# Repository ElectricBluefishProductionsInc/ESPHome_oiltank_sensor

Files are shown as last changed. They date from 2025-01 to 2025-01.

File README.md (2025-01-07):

# ESPHome Oil Tank Level Monitor

This project uses ESPHome to configure an ESP32 device for monitoring the oil level in a tank. The device utilizes a VL53L0X distance sensor to measure the distance to the oil surface and calculates the remaining oil volume, daily consumption, and estimated time to depletion. Integration with Home Assistant provides real-time data visualization and tracking.
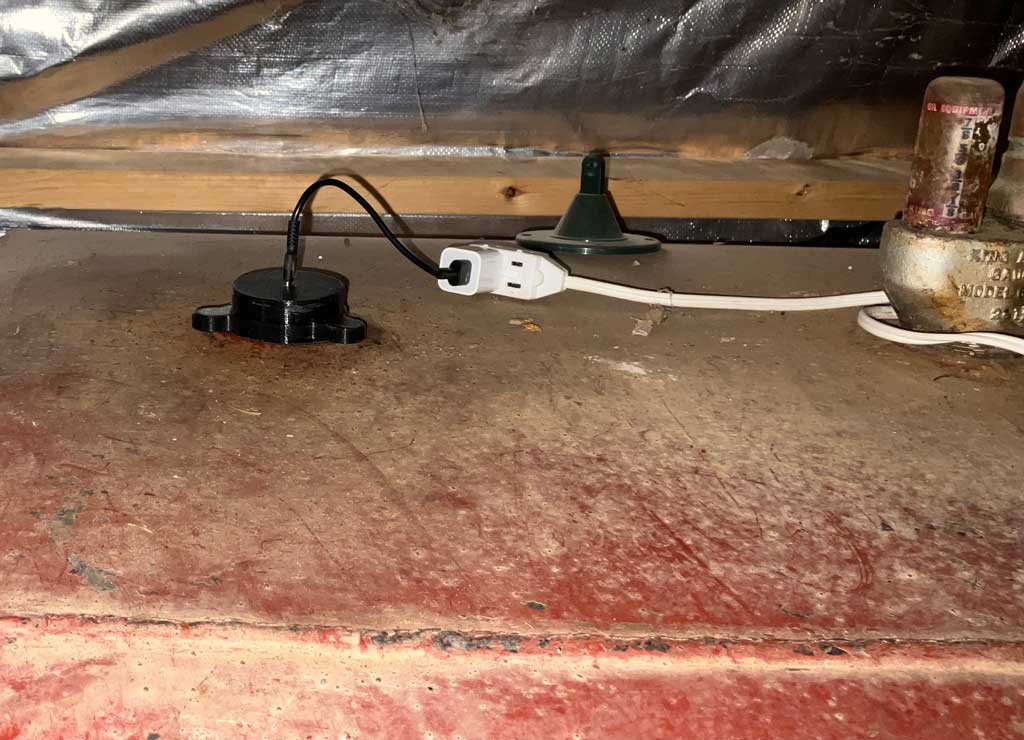
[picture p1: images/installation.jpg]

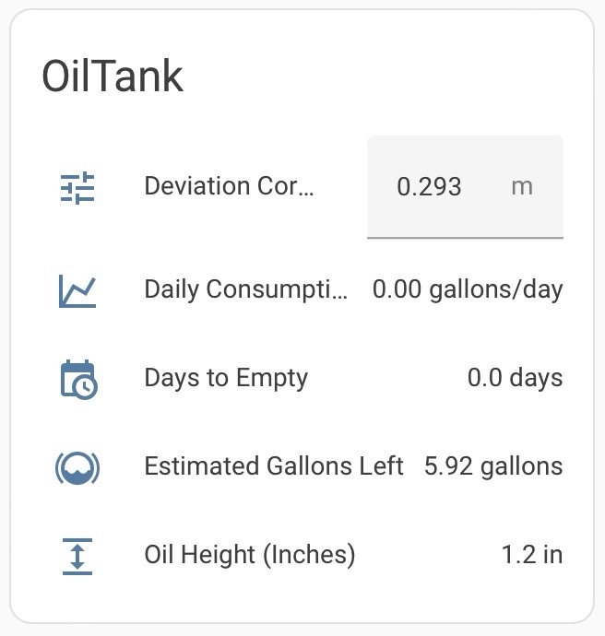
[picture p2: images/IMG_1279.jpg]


## Features

- **Real-Time Monitoring**: Tracks oil height, volume, daily consumption, and estimated days until empty.
- **VL53L0X Sensor Integration**: Measures distance to the oil surface using I2C.
- **Customizable Deviation Correction**: Adjusts measurements for environmental or sensor-specific deviations.
- **Daily Consumption Tracking**: Logs hourly changes to calculate daily oil usage.
- **WiFi Connectivity**: Includes fallback access point (AP) mode for easy troubleshooting.
- **Home Assistant API**: Secure integration with Home Assistant using encrypted communication.
- **Over-The-Air (OTA) Updates**: Enables secure firmware updates.

## Sensors

- **VL53L0X Sensor**: Measures raw distance to the oil surface.
- **Template Sensors**:
  - Oil height in inches.
  - Estimated gallons remaining.
  - Daily consumption rate in gallons/day.
  - Days until the tank is empty.

## Number Component

Allows manual adjustment of deviation correction via Home Assistant.

## Hardware Requirements

- **ESP32-C3 DevKitM-1**
    https://a.aliexpress.com/_mtii2Ax
  - **VL53L0X Distance Sensor**
    http://t.ly/2mWMY
- Oil tank dimensions (customizable in the YAML file).

## Installation Instructions

1. **Hardware Setup**:
   - Connect the VL53L0X sensor to the ESP32 on the specified I2C pins (GPIO 4 for SDA and GPIO 5 for SCL).
   - Ensure the sensor is mounted securely above the oil tank.

2. **ESPHome Configuration**:
   - Clone this repository or copy the YAML file into your ESPHome project.
   - Update the WiFi credentials and secure keys as needed.

3. **Compile and Deploy**:
   - Use ESPHome to compile and upload the YAML configuration to the ESP32.
   - Add the device to Home Assistant using the API.

4. **Calibrate**:
   - Adjust the `deviation_correction` value to ensure accurate oil level measurements.

## Monitoring and Usage

- **Home Assistant Dashboard**:
  - Monitor real-time oil height, volume, and usage trends.
  - View the estimated time until empty based on daily consumption.

- **Adjustable Parameters**:
  - Modify the deviation correction or other global variables as needed via Home Assistant.

## Notes

- Ensure proper alignment of the VL53L0X sensor for accurate readings.
- Regularly check the daily consumption sensor to optimize usage and plan refills.
- Use the OTA feature to deploy updates without reconnecting the device to your computer.

## License

This project is licensed under the [MIT License](LICENSE).

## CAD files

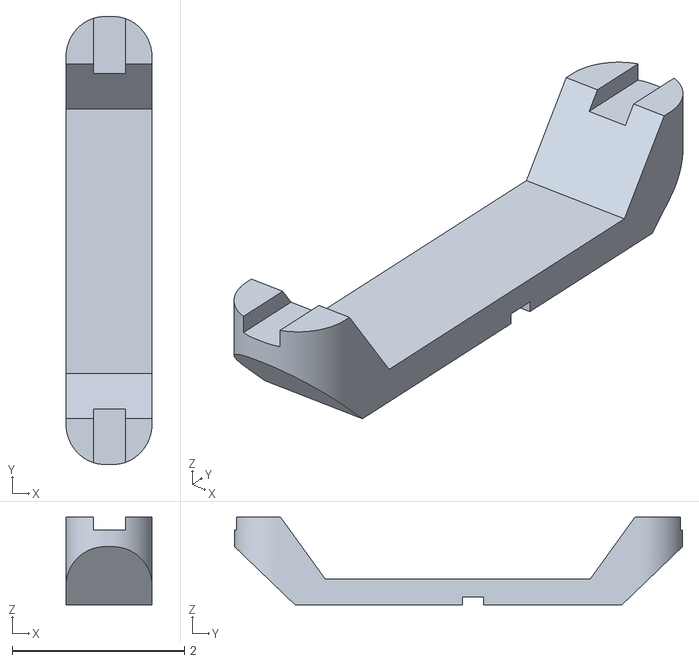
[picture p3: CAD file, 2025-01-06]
print_model/Oil_sensor_esp32-c_internal_support_shelf.stl
1.00 x 5.20 x 1.02

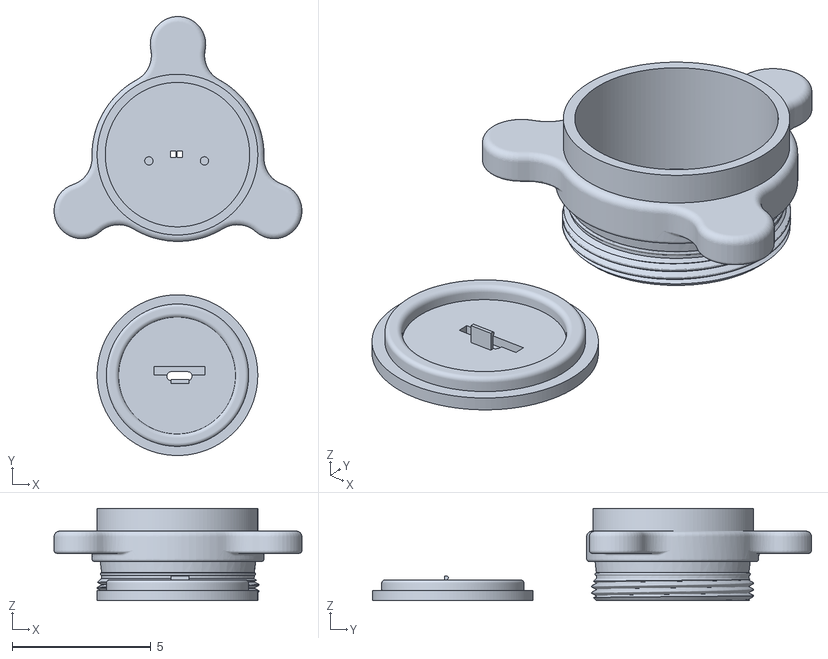
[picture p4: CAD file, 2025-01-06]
print_model/Oil_sensor_case.stl
8.92 x 15.8 x 3.31

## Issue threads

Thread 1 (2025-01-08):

The Deviation on the sensor distance might NOT be constant.

ElectricBluefishProductionsInc, 2025-01-08:
The Deviation on the sensor distance might NOT be constant. If the reported distance accuracy changes with the amount  fuel in the tank, a more involved computation may need to be created. I need feed back over time to determine if this is a significant issue with the sensor.

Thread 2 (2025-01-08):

UI issue: The deviation setting is cryptic to the end user.

ElectricBluefishProductionsInc, 2025-01-08:
The value, currently 0.293, is ambiguous and confusing. it is actually adjusting the raw data which is collected in meters, but the user wants to see the data in inches of centimeter. Should I add to the number to correct to my or subtract? By how much?

The interface needs to be changed to make this more obvious. Maybe a +/- or a slider to add distance or remove distance. Control the input by make the changes in .001 increments? This is a UI issue.

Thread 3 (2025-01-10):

The inches data gets erratic when the tank approaches empty

ElectricBluefishProductionsInc, 2025-01-10:
As of  b3cdaf5…a173045.
The inch count starts rising significantly. actual depth 1" or less, reported depth 6+". Added 5 gallons and the data returned to anticipated value.

The sensor accuracy is not fantastic. It seems to range +- as much as a inch at times. With filter running, the deviation is about ~1/4" at best.  I suspect that a simple deviation correction is not going to be adequate. Probably will require a correction curve or sorts to adjust based on the  distance the sensor is from the oil surface. So far **NOT** impressed with this sensor hardeware.

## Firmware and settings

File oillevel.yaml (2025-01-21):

esphome:
  name: oiltank
  friendly_name: OilTank

esp32:
  board: esp32-c3-devkitm-1
  framework:
    type: arduino

# Enable logging
logger:
  level: INFO

# Enable Home Assistant API
api:
  encryption:
    key: !secret api_key

ota:
  password: !secret ota_password

wifi:
  ssid: 6}9rNeV:C2AZqx1Z-2
  password: !secret wifi_password

  ap:
    ssid: "Oiltank Fallback Hotspot"
    password: "yMcTRdTM2tT7"

captive_portal:

# Enable i2c for the VL53L0X sensor
i2c:
  sda: 4
  scl: 5
  scan: true

globals:
  - id: tank_height
    type: float
    initial_value: "27.6"  # Tank height in inches
  - id: tank_width
    type: float
    initial_value: "44.0"  # Tank width in inches
  - id: tank_length
    type: float
    initial_value: "60.0"  # Tank depth (length) in inches
  - id: deviation_correction
    type: float
    initial_value: "0.256"  # Deviation correction in meters
  - id: total_daily_consumption
    type: float
    initial_value: "0.0"  # Average valid daily consumption in gallons
  - id: previous_height
    type: float
    initial_value: "0.0"  # Store the last oil height for comparison

time:
  - platform: homeassistant
    id: homeassistant_time
    on_time:
      - seconds: 0
        minutes: 0
        then:
          - lambda: |-
              static std::array<float, 24> oil_height_values = {0.0};
              static std::array<float, 24> valid_consumptions = {0.0};

              float current_height = id(oil_height_inches).state;

              // Add current height to the list
              for (int i = oil_height_values.size() - 1; i > 0; i--) {
                oil_height_values[i] = oil_height_values[i - 1];
              }
              oil_height_values[0] = current_height;

              // Calculate hourly consumption values
              for (int i = 1; i < oil_height_values.size(); i++) {
                float consumption = oil_height_values[i - 1] - oil_height_values[i];

                // Filter out NaN, negative values, and outliers (> 8 gallons/day)
                if (!isnan(consumption) && consumption >= 0.0 && consumption <= 8.0 / 24.0) {
                  valid_consumptions[i - 1] = consumption;
                } else {
                  valid_consumptions[i - 1] = 0.0;
                }
              }

              // Calculate average daily consumption
              float sum = 0.0;
              int count = 0;
              for (auto value : valid_consumptions) {
                if (value > 0.0) {
                  sum += value;
                  count++;
                }
              }
              if (count > 0) {
                id(total_daily_consumption) = sum * 24.0 / count;  // Project daily rate
              } else {
                id(total_daily_consumption) = 0.0;  // No valid data
              }

              ESP_LOGD("Daily Consumption", "Valid Data Points: %d, Projected Daily Consumption: %.2f gallons",
                       count, id(total_daily_consumption));

sensor:
  - platform: wifi_signal
    name: "WiFi Signal Strength"
    update_interval: 60s
  - platform: vl53l0x
    name: "Raw Oil Distance (m)"
    address: 0x29
    id: raw_oil_distance
    update_interval: 5s
    accuracy_decimals: 2
    unit_of_measurement: "m"
    icon: "mdi:oil-level"
    internal: true
    filters:
      - lambda: |-
          static bool filtering_enabled = true;

          // Thresholds in meters
          const float lower_threshold = 0.00762;  // 0.3 inches
          const float upper_threshold = 0.0381;  // 1.5 inches

          if (x < lower_threshold) {
            filtering_enabled = false;  // Disable filtering
          } else if (x > upper_threshold) {
            filtering_enabled = true;  // Enable filtering
          }

          if (filtering_enabled) {
            // Apply Kalman filtering
            static float estimate = 0.0;
            static float estimate_error = 1.0;
            static float process_noise = 0.03;  // Adjust for your sensor
            static float measurement_noise = 0.1;  // Adjust for your sensor

            float kalman_gain = estimate_error / (estimate_error + measurement_noise);
            estimate = estimate + kalman_gain * (x - estimate);
            estimate_error = (1.0 - kalman_gain) * estimate_error + fabs(estimate - x) * process_noise;

            return estimate;
          } else {
            // Return raw value when filtering is disabled
            return x;
          }

  - platform: template
    name: "Oil Height (Inches)"
    id: oil_height_inches
    unit_of_measurement: "in"
    accuracy_decimals: 2
    lambda: |-
      float raw_distance_m = id(raw_oil_distance).state;  // Raw sensor distance in meters
      float correction_m = id(deviation_correction);      // Deviation correction in meters
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

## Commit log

2025-01-06 Added STL File to fit 2" pipe threaded opening. The support file is to aid in holding the ESP32 in the usb-c slot. There is a small amount of post printing prep to make the esp32 fit in place.
    [Oil_sensor_case.stl, Oil_sensor_esp32-c_internal_support_shelf.stl]
2025-01-06 Added a photo of the device installation
2025-01-07 Bugfix: The daily consumption calculation was completely wrong. Also removed the raw level output as it is meaningless for day to day use.
    [oillevel.yaml]
2025-01-07 Bugfix: The daily consumption calculation was completely wrong. Also removed the raw level output as it is meaningless for day to day use. & fixed compiling error.
    [oillevel.yaml]
2025-01-07 Added the sensor readout image
2025-01-08 added a reboot switch for debug.
    [oillevel.yaml]
2025-01-08 Chnaged the switch reboot to switch clear accumulated data.
    [oillevel.yaml]
2025-01-19 added an edit to the raw sensor filter to disable when the level is below.3
